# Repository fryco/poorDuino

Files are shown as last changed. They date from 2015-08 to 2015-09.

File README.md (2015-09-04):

# poorDuino
Arduino-like simple development board

## Idea
Main purpose of designing `poorDuino` was to *utilize* dozen Atmega8/Atmega168 chips, which were collected by me, for last few years. I do like Arduino as a form factor and don't like as IDE. Thus I decided to design this board to fulfil my not so sophisticated expectations: keep compatibility with original Arduino Uno and no support for programming via USB (ISP FTW!).

`poorDuino`'s name comes from reduced manufacturing costs (i.e. no USB programmer onboard). It might be decreased more, but it would not fulfill my needs.

##Features
* Arduino UNO board shape,
* Connectors are fully compatible with Arduino standard,
* Two power supply: 5V and 3V3 (selected via jumper),
* Extra pull-up resitors on IIC lines (enabled by soldering jumper on bottom of the board),
* USB connector and USB2UART bridge removed,
* ICSP connector for programming (external programmer is necessary)

## Resources
1. Arduino UNO https://www.arduino.cc/en/Main/arduinoBoardUno

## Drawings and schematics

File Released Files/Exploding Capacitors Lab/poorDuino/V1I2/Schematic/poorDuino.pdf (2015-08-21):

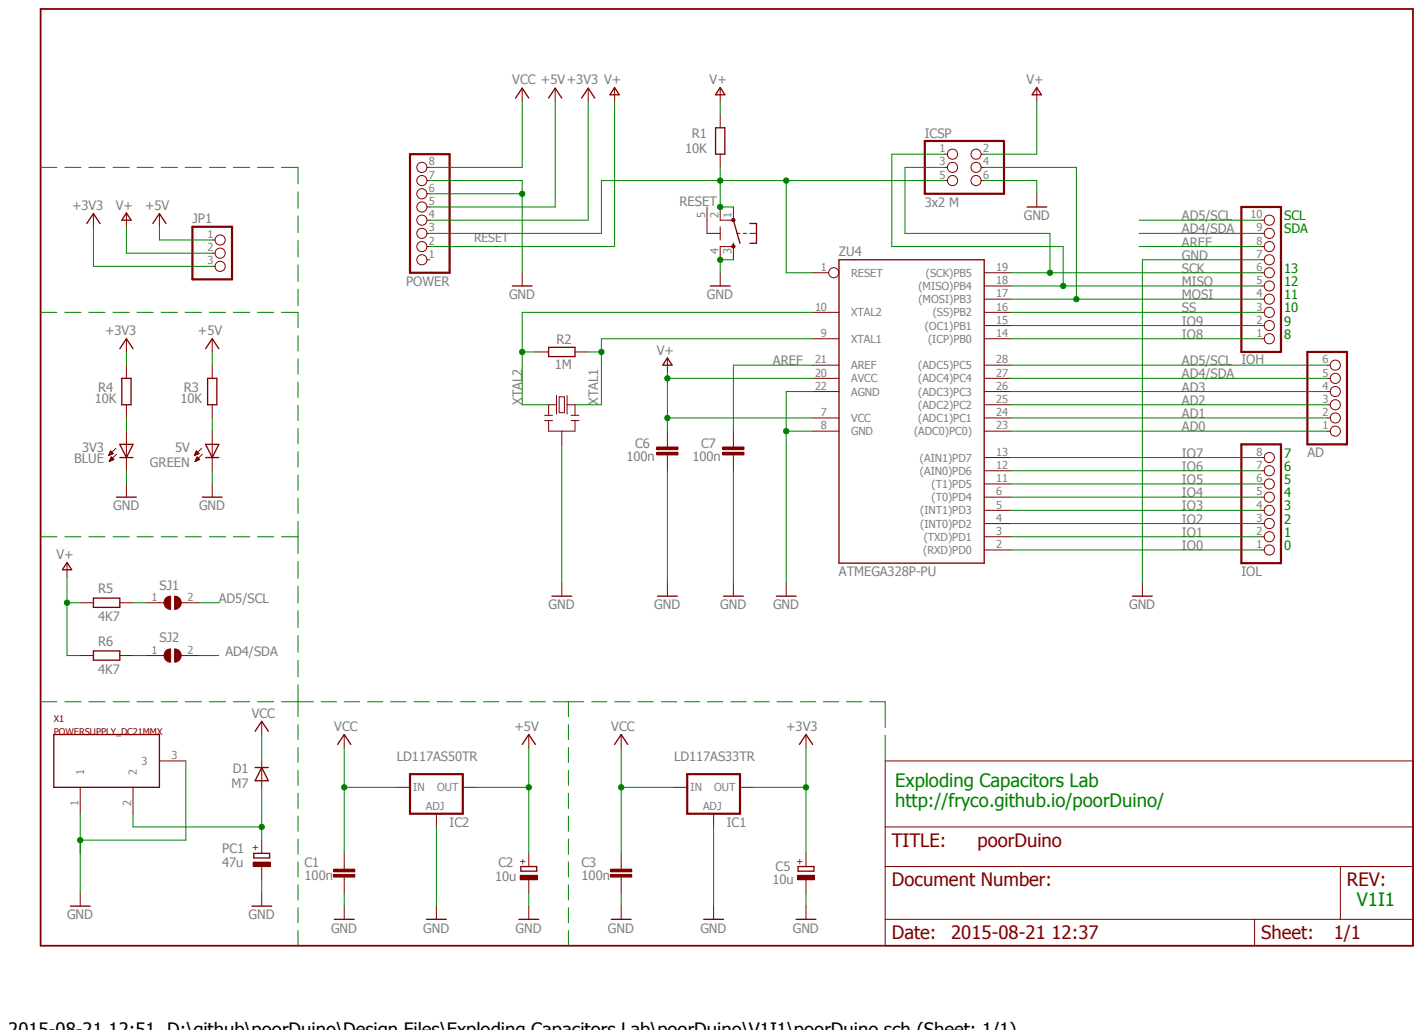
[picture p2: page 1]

Exploding Capacitors Lab
http://fryco.github.io/poorDuino/

Document Number: | REV: V1I1

Date: 2015-08-21 12:37 | Sheet: 1/1

2015-08-21 12:51 D:\github\poorDuino\Design Files\Exploding Capacitors Lab\poorDuino\V1I1\poorDuino.sch (Sheet: 1/1)

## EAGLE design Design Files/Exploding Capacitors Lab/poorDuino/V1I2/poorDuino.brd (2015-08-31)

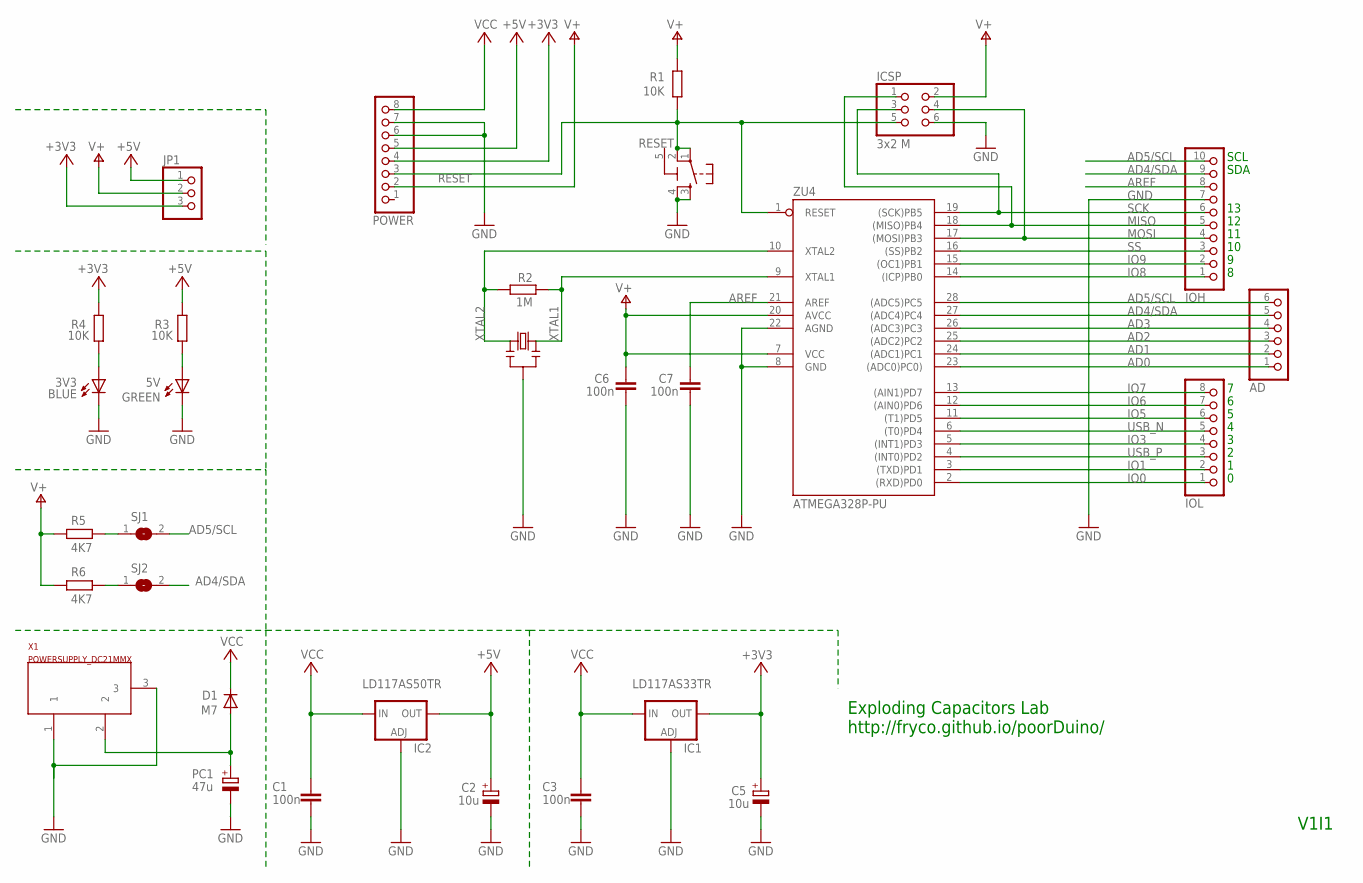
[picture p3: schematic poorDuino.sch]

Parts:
3V3: BLUE; CHIP-LED0805
5V: GREEN; CHIP-LED0805
AD: 6x1F-H8.5; 1X06
C1, C3, C6, C7: 100n; C0805
C2, C5: 10u; SMC_A
D1: M7; SMB
IC1: LD117AS33TR; SOT223
IC2: LD117AS50TR; SOT223
ICSP: 3x2 M; 2X03
IOH: 10x1F-H8.5; 1X10
IOL: 8x1F-H8.5; 1X08
JP1: PINHD-1X3; 1X03
PC1: 47u; PANASONIC_D
POWER: 8x1F-H8.5; 1X08
R1, R3, R4: 10K; R0805
R2: 1M; R0805
R5, R6: 4K7; R0805
RESET: TS42031-160R-TR-7260; TS42
SJ1, SJ2: SJ
X1: POWERSUPPLY_DC21MMX; POWERSUPPLY_DC-21MM
Y2: CSTCE16M0V53-R0 16MHZ; RESONATOR
ZU4: ATMEGA328P-PU; DIL28-3

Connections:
5-GND: RESET.5 (5-GND)
+3V3: C5.+, IC1.4 (OUT), JP1.3, POWER.4, R4.1
+5V: C2.+, IC2.4 (OUT), JP1.1, POWER.5, R3.1
AD0: AD.1, ZU4.23 ((ADC0)PC0))
AD1: AD.2, ZU4.24 ((ADC1)PC1)
AD2: AD.3, ZU4.25 ((ADC2)PC2)
AD3: AD.4, ZU4.26 ((ADC3)PC3)
AD4/SDA: AD.5, IOH.9, SJ2.2, ZU4.27 ((ADC4)PC4)
AD5/SCL: AD.6, IOH.10, SJ1.2, ZU4.28 ((ADC5)PC5)
AREF: C7.2, IOH.8, ZU4.21 (AREF)
GND: 3V3.C, 5V.C, C1.1, C2.-, C3.1, C5.-, C6.1, C7.1, IC1.1 (ADJ), IC2.1 (ADJ), ICSP.6, IOH.7, PC1.-, POWER.6, POWER.7, RESET.3, RESET.4, X1.1, X1.3, Y2.2, ZU4.8 (GND), ZU4.22 (AGND)
IO0: IOL.1, ZU4.2 ((RXD)PD0)
IO1: IOL.2, ZU4.3 ((TXD)PD1)
IO3: IOL.4, ZU4.5 ((INT1)PD3)
IO5: IOL.6, ZU4.11 ((T1)PD5)
IO6: IOL.7, ZU4.12 ((AIN0)PD6)
IO7: IOL.8, ZU4.13 ((AIN1)PD7)
IO8: IOH.1, ZU4.14 ((ICP)PB0)
IO9: IOH.2, ZU4.15 ((OC1)PB1)
MISO: ICSP.1, IOH.5, ZU4.18 ((MISO)PB4)
MOSI: ICSP.4, IOH.4, ZU4.17 ((MOSI)PB3)
unnamed: 3V3.A, R4.2
unnamed: 5V.A, R3.2
unnamed: R5.1, SJ1.1
unnamed: R6.1, SJ2.1
PWRIN: D1.A, PC1.+, X1.2
RESET: ICSP.5, POWER.3, R1.1, RESET.1, RESET.2, ZU4.1 (RESET)
SCK: ICSP.3, IOH.6, ZU4.19 ((SCK)PB5)
SS: IOH.3, ZU4.16 ((SS)PB2)
USB_N: IOL.5, ZU4.6 ((T0)PD4)
USB_P: IOL.3, ZU4.4 ((INT0)PD2)
V+: C6.2, ICSP.2, JP1.2, POWER.2, R1.2, R5.2, R6.2, ZU4.7 (VCC), ZU4.20 (AVCC)
VCC: C1.2, C3.2, D1.C, IC1.3 (IN), IC2.3 (IN), POWER.8
XTAL1: R2.1, Y2.3, ZU4.9 (XTAL1)
XTAL2: R2.2, Y2.1, ZU4.10 (XTAL2)

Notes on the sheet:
Exploding Capacitors Lab http://fryco.github.io/poorDuino/
SDA
SCL
V1I1

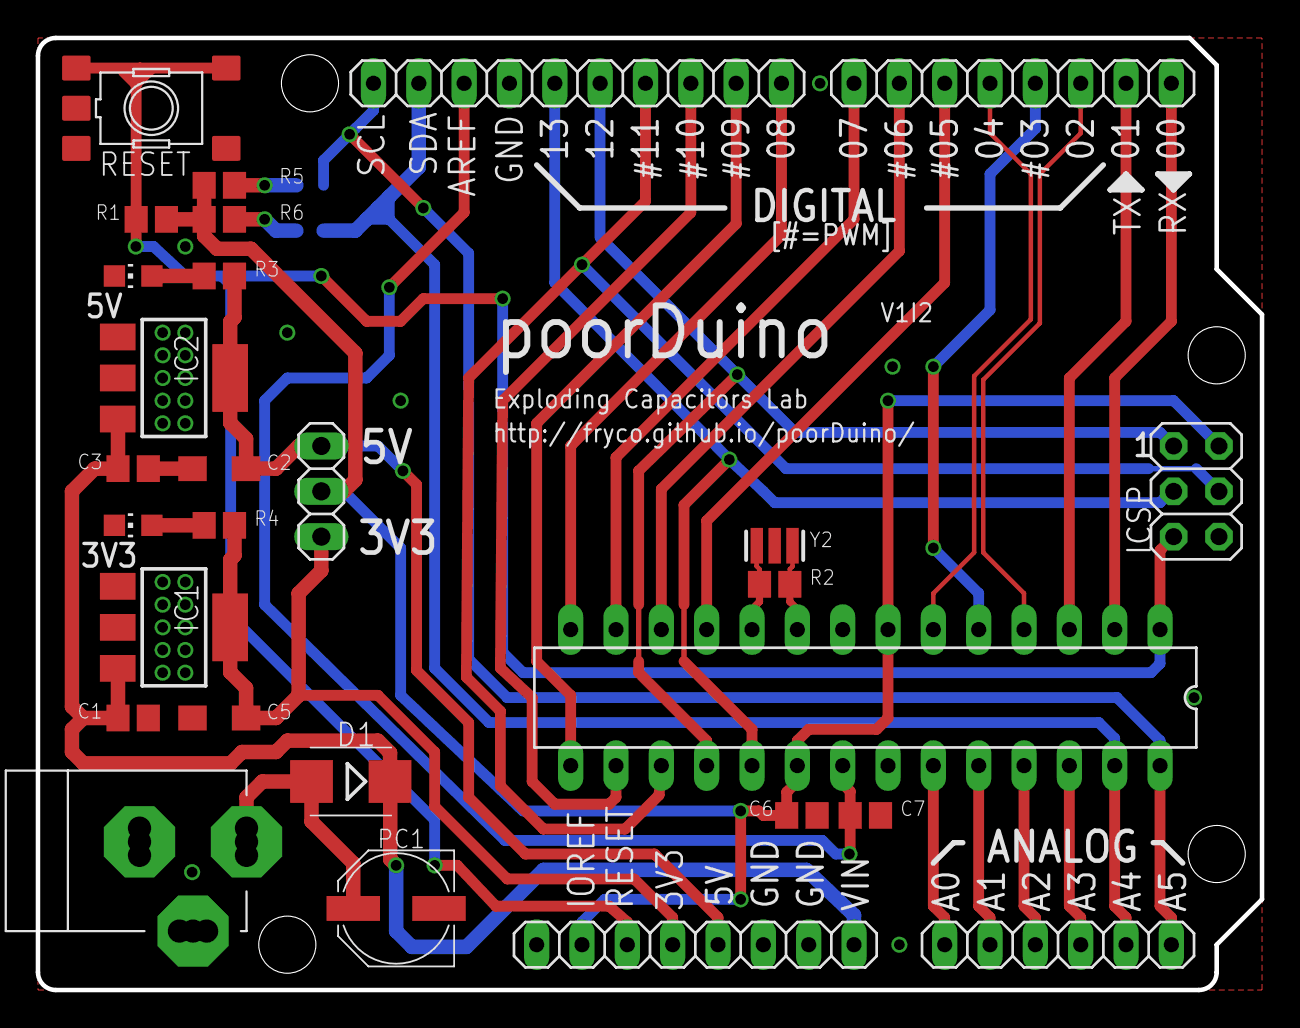
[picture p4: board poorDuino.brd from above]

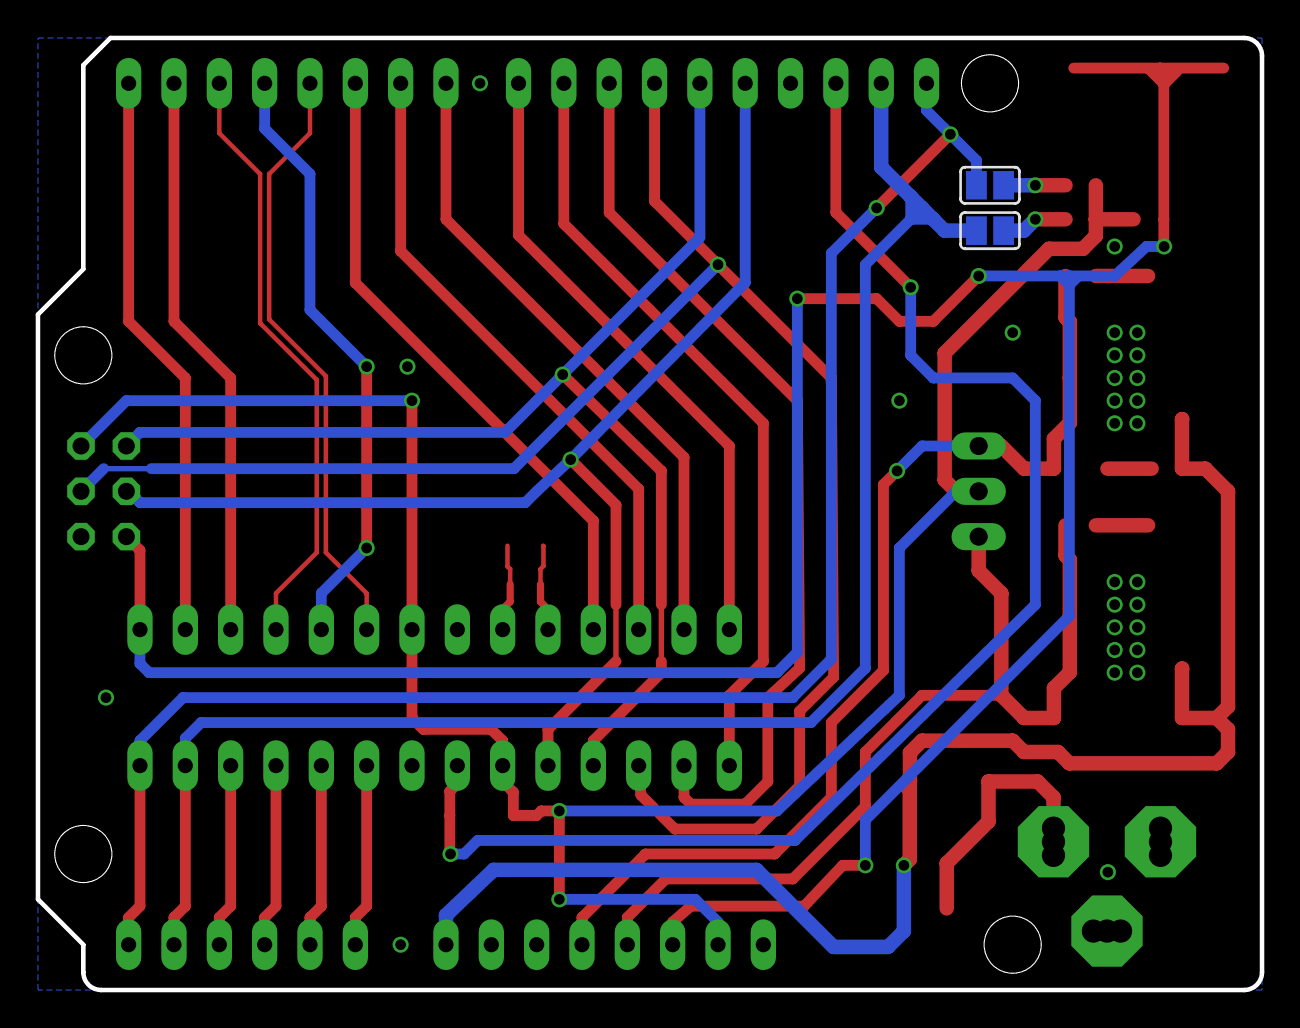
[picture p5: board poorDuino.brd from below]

Board: 2 copper layers, 68.6 x 53.3 mm, 30 parts (2 on the bottom side), 34 nets.

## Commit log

2015-08-19 Directory tree update
    [arduino_Uno_Rev3-02-TH.brd, arduino_Uno_Rev3-02-TH.sch, poorDuino.brd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]
2015-08-19 Atmega16U2 with surroundings removed
    [poorDuino.brd, poorDuino.sch]
2015-08-19 Power supply modification
    LDOs, which were originaly in Arduino project, have been replaced to
    LD1117xxx. /schematic only/
    [poorDuino.brd, poorDuino.sch]
2015-08-19 Schematic cleanup
    3V3 LED status added
    [poorDuino.brd, poorDuino.sch]
2015-08-19 First attempt to PCB design
    [poorDuino.brd, poorDuino.sch]
2015-08-20 PCB layout
    [poorDuino.brd, poorDuino.sch]
2015-08-20 PCB layout update
    [poorDuino.brd]
2015-08-21 PCB update
    [poorDuino.brd]
2015-08-21 SCH update
    [poorDuino.sch]
2015-08-21 V1I1 is ready!
    [poorDuino.GBL, poorDuino.GBO, poorDuino.GBP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]
2015-08-21 Release files update
    [poorDuino.GBO]
2015-08-27 PCB layout improvement
    - Better grounding
    - Re-alignment of few elements/routes
    - Removed useless labels from the bottom of the board
    - RCL labels alignment
    [poorDuino.brd]
2015-08-31 V1I2 branched out
    [poorDuino.brd, poorDuino.sch]
2015-08-31 Differential pair routing applied to traces related to V-USB support (DIO2 and DIO4)
    [poorDuino.brd, poorDuino.sch]
2015-08-31 Dir structure update
    [poorDuino.brd, poorDuino.sch]
2015-08-31 V1I1 design files were missing. Added them back to repo.
    [poorDuino.brd, poorDuino.sch]
2015-08-31 PCB layout V1I2 is ready
    [poorDuino.brd]
2015-08-31 V1I2 release files update.
    [poorDuino.GBL, poorDuino.GBO, poorDuino.GBP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]
